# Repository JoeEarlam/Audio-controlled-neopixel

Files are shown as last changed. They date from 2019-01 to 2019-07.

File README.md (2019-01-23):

# Audio-controlled-neopixel

Filters an incoming line level audio signal into three bandpassed frequency "bins", which output to a peak detect sample and hold circuit. These sample and holds are sampled by the Arduino ADC, and the three frequencies (bass, mid, treble) become RGB on a Neopixel compatible LED strip.

There are a few different patterns currently written - a mixture of sound activated, random, block updated and "chasing lights" patterns.

# Hardware Notes, in no particular order.

There are two options for power. +5V only using a Tracopower TMA0512D to generate the +/-12V voltages required for the analogue components, or external +/-12V and 5V. 5V only is preferred for simplicity, but the TMA0512D isn't a typical parts bin find (and is the single most expensive component on the board), so an external power header has been added for operation without.

The level potentiometer allows a wide range of signals to be used. Turn it up until the peak light begins to flash, then down a little. This gives you maximum brightness from the Neopixel strip without clipping.

Follow Adafruit's guidance on Neopixel power supplies - the 5V rail will need to be beefy. The PCB can handle up to around 5A - ensure the fitted fuse is suitable.

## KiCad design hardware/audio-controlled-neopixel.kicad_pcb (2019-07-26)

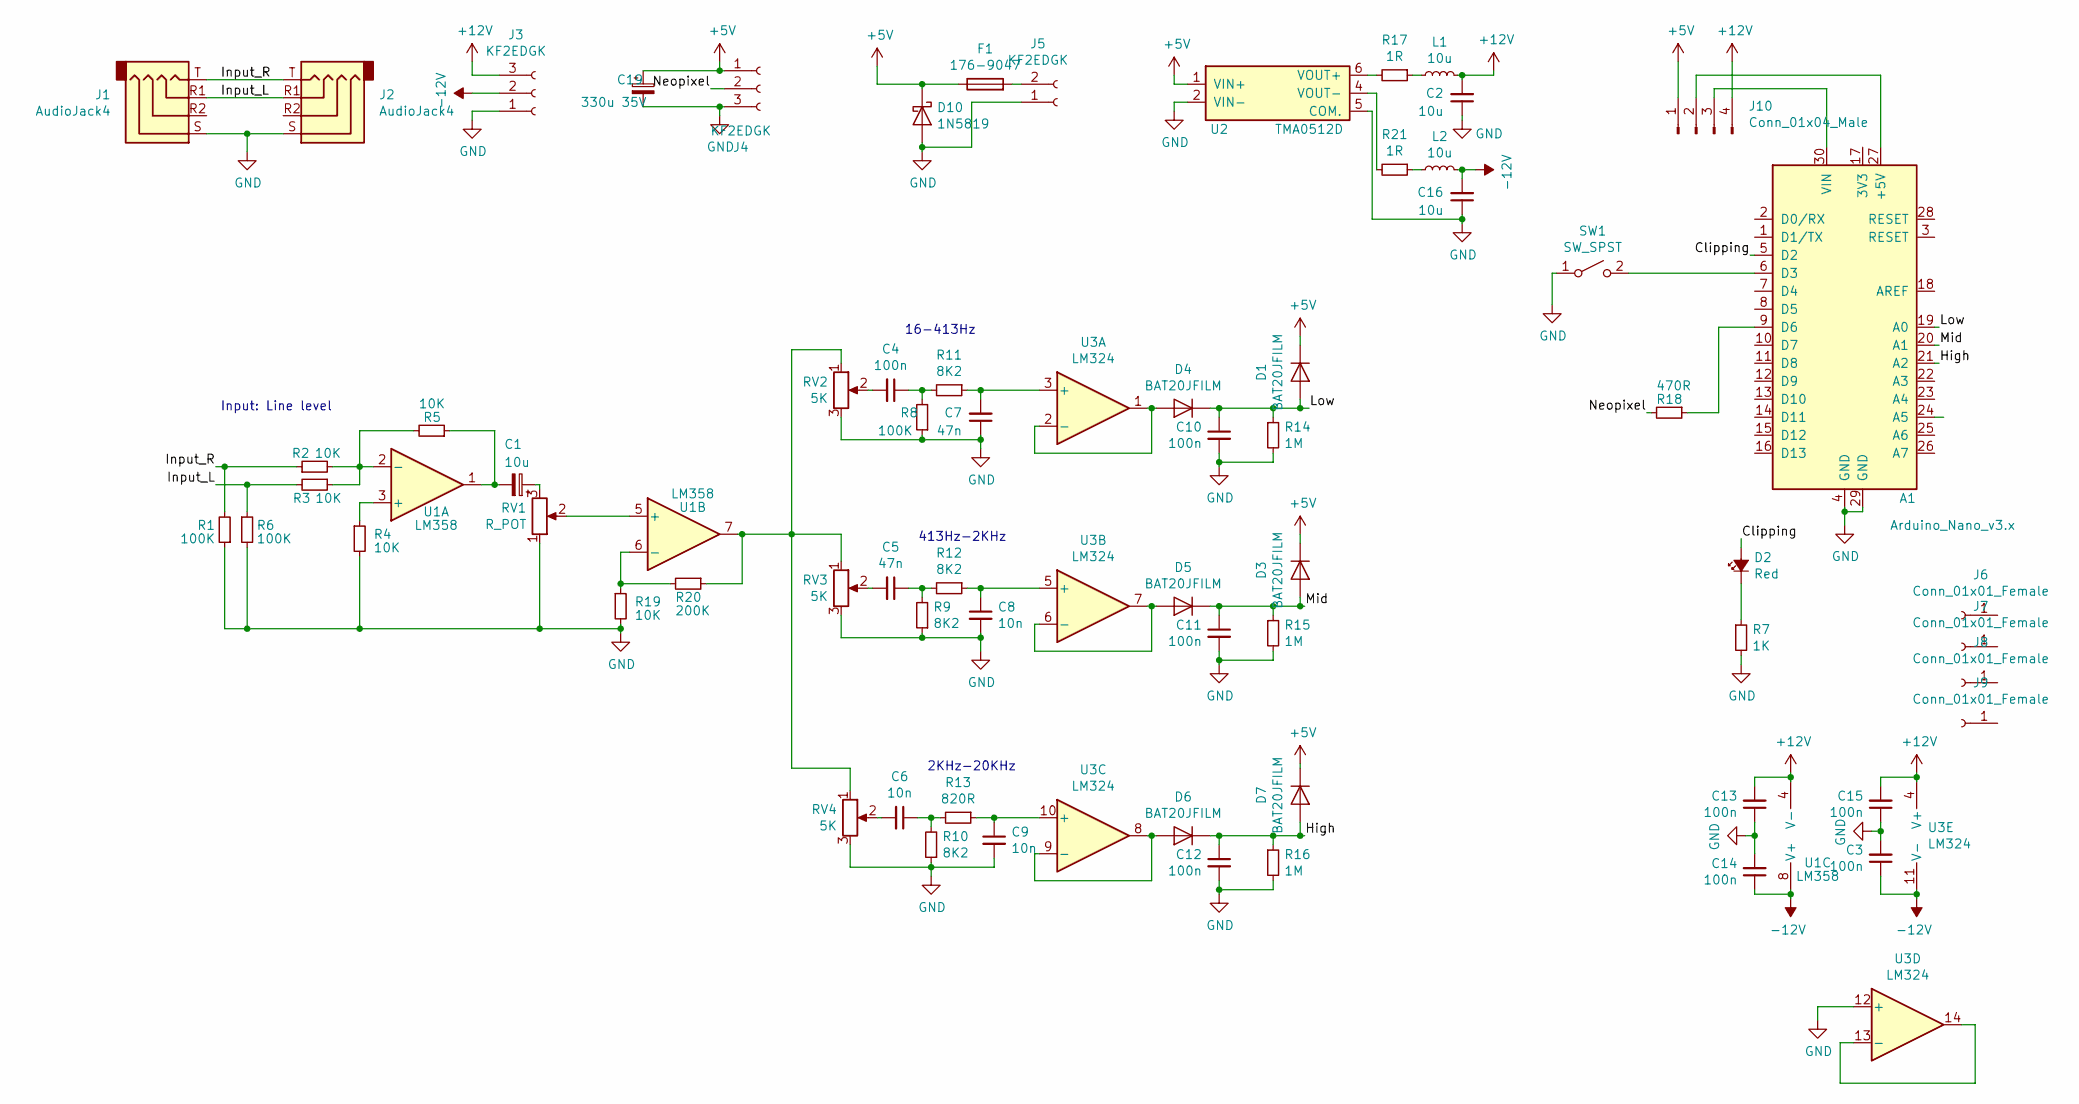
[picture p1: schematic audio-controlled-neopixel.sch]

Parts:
A1: Arduino_Nano_v3.x; Arduino_Nano
C1: 10u; CP_Radial_D5.0mm_P2.00mm
C2, C16: 10u; C_0805_2012Metric
C3, C4, C10, C11, C12, C13, C14, C15: 100n; C_0805_2012Metric
C5, C7: 47n; C_0805_2012Metric
C6, C8, C9: 10n; C_0805_2012Metric
C19: 330u 35V; CP_Elec_10x10
D1, D3, D4, D5, D6, D7: BAT20JFILM; D_SOD-323
D2: Red; LED_0805_2012Metric
D10: 1N5819; D_SOD-123
F1: 176-9047; 5x20_holder
J1, J2: AudioJack4; Jack_3.5mm_PJ320D_Horizontal
J3: KF2EDGK; TerminalBlock_Phoenix_MPT-0,5-3-2.54_1x03_P2.54mm_Horizontal
J4: KF2EDGK; PhoenixContact_MSTBA_2,5_3-G-5,08_1x03_P5.08mm_Horizontal
J5: KF2EDGK; PhoenixContact_MSTBA_2,5_2-G_1x02_P5.00mm_Horizontal
J6, J7, J8, J9: Conn_01x01_Female; MountingHole_3.2mm_M3
J10: Conn_01x04_Male; PinHeader_1x04_P2.54mm_Vertical
L1, L2: 10u; L_0805_2012Metric
R1, R6, R8: 100K; R_0805_2012Metric
R2, R3, R4, R5, R19: 10K; R_0805_2012Metric
R7: 1K; R_0805_2012Metric
R9, R10, R11, R12: 8K2; R_0805_2012Metric
R13: 820R; R_0805_2012Metric
R14, R15, R16: 1M; R_0805_2012Metric
R17, R21: 1R; R_0805_2012Metric
R18: 470R; R_0805_2012Metric
R20: 200K; R_0805_2012Metric
RV1: R_POT; Potentiometer_Alps_RK097_Single_Horizontal
RV2, RV3, RV4: 5K; Potentiometer_Vishay_TS53YJ_Vertical; Part Number EVM3YSX50B53
SW1: SW_SPST; SW_Tactile_SKHH_Angled
U1: LM358; SOIC-8_3.9x4.9mm_P1.27mm
U2: TMA0512D; TMAxxxxD; Manufacturer_Part_Number TMA 2412D; Mouser Part Number 495-TMA-2412D
U3: LM324; SOIC-14_3.9x8.7mm_P1.27mm

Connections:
+5V: C19.1, D1.1 (K), D3.1 (K), D7.1 (K), D10.1 (K), F1.1, J4.1, J10.1, U2.1 (VIN+)
+12V: C2.2, C13.2, C15.2, J3.3, J10.4, L1.2, U1.4 (V-), U3.4 (V+)
-12V: C3.1, C14.1, C16.2, J3.2, L2.2, U1.8 (V+), U3.11 (V-)
/Clipping: A1.5 (D2), D2.2 (A)
/High: A1.21 (A2), C12.1, D6.1 (K), D7.2 (A), R16.1
/Input_L: J1.R1, J2.R1, R3.2, R6.1
/Input_R: J1.T, J2.T, R1.2, R2.1
/Low: A1.19 (A0), C10.1, D1.2 (A), D4.1 (K), R14.1
/Mid: A1.20 (A1), C11.1, D3.2 (A), D5.1 (K), R15.1
/Neopixel: J4.2, R18.2
GND: A1.4 (GND), A1.29 (GND), C2.1, C3.2, C7.1, C8.2, C9.2, C10.2, C11.2, C12.2, C13.1, C14.2, C15.1, C16.1, C19.2, D10.2 (A), J1.S, J2.S, J3.1, J4.3, J5.1, R1.1, R4.2, R6.2, R7.2, R8.1, R9.1, R10.1, R14.2, R15.2, R16.2, R19.2, RV1.1, RV2.3, RV3.3, RV4.3, SW1.1 (A), U2.2 (VIN-), U2.5 (COM.), U3.12 (+)
unnamed: A1.6 (D3), SW1.2 (B)
unnamed: A1.9 (D6), R18.1
unnamed: A1.27 (+5V), J10.2
unnamed: A1.30 (VIN), J10.3
unnamed: C1.1, RV1.3
unnamed: C1.2, R5.1, U1.1
unnamed: C4.1, R8.2, R11.2
unnamed: C4.2, RV2.2
unnamed: C5.1, R9.2, R12.2
unnamed: C5.2, RV3.2
unnamed: C6.1, R10.2, R13.2
unnamed: C6.2, RV4.2
unnamed: C7.2, R11.1, U3.3 (+)
unnamed: C8.1, R12.1, U3.5 (+)
unnamed: C9.1, R13.1, U3.10 (+)
unnamed: D2.1 (K), R7.1
unnamed: D4.2 (A), U3.1, U3.2 (-)
unnamed: D5.2 (A), U3.6 (-), U3.7
unnamed: D6.2 (A), U3.8, U3.9 (-)
unnamed: F1.2, J5.2
unnamed: L1.1, R17.1
unnamed: L2.1, R21.1
unnamed: R2.2, R3.1, R5.2, U1.2 (-)
unnamed: R4.1, U1.3 (+)
unnamed: R17.2, U2.6 (VOUT+)
unnamed: R19.1, R20.2, U1.6 (-)
unnamed: R20.1, RV2.1, RV3.1, RV4.1, U1.7
unnamed: R21.2, U2.4 (VOUT-)
unnamed: RV1.2, U1.5 (+)
unnamed: U3.13 (-), U3.14

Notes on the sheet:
16-413Hz
413Hz-2KHz
2KHz-20KHz
Input: Line level

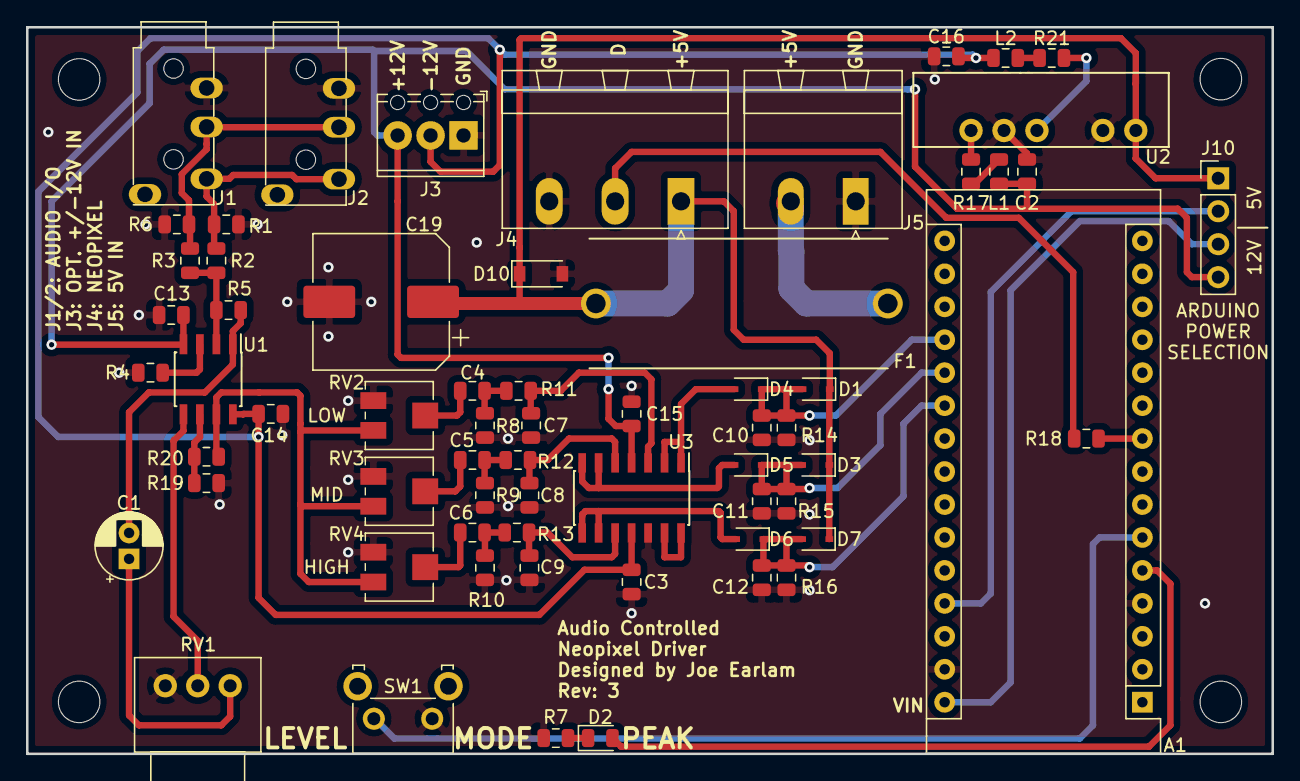
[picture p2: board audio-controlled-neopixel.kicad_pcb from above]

Board: 2 copper layers, 96.0 x 56.0 mm, 68 parts (0 on the bottom side), 41 nets.

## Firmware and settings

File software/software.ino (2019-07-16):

#include <Adafruit_NeoPixel.h>
#ifdef __AVR__
  #include <avr/power.h>
#endif


/////////////////////////Number of pixels in your strip
const byte numpixels = 152; 

const byte clipping = 2;
const byte button = 3;        //button pin
const byte pin = 6;           //Neopixel pin

boolean buttonState;          //current state of button
boolean lastButtonState;      //previous state of button

byte red;                     //red pixel value
byte green;                   //green...
int blue;                    //etc
byte programme;               //current programme type (0 = block, 1 = chasing lights)

byte pixelarray[numpixels][3];    //2D Array to hold status of every pixel

Adafruit_NeoPixel pixels = Adafruit_NeoPixel(numpixels, pin, NEO_RGB + NEO_KHZ800);		//set up strip


//Table for gamma correction, this adjusts brightness values for more visual contrast
const uint8_t PROGMEM gamma8[] = {
    0,  0,  0,  0,  0,  0,  0,  0,  0,  0,  0,  0,  0,  0,  0,  0,
    0,  0,  0,  0,  0,  0,  0,  0,  0,  0,  0,  0,  1,  1,  1,  1,
    1,  1,  1,  1,  1,  1,  1,  1,  1,  2,  2,  2,  2,  2,  2,  2,
    2,  3,  3,  3,  3,  3,  3,  3,  4,  4,  4,  4,  4,  5,  5,  5,
    5,  6,  6,  6,  6,  7,  7,  7,  7,  8,  8,  8,  9,  9,  9, 10,
   10, 10, 11, 11, 11, 12, 12, 13, 13, 13, 14, 14, 15, 15, 16, 16,
   17, 17, 18, 18, 19, 19, 20, 20, 21, 21, 22, 22, 23, 24, 24, 25,
   25, 26, 27, 27, 28, 29, 29, 30, 31, 32, 32, 33, 34, 35, 35, 36,
   37, 38, 39, 39, 40, 41, 42, 43, 44, 45, 46, 47, 48, 49, 50, 50,
   51, 52, 54, 55, 56, 57, 58, 59, 60, 61, 62, 63, 64, 66, 67, 68,
   69, 70, 72, 73, 74, 75, 77, 78, 79, 81, 82, 83, 85, 86, 87, 89,
   90, 92, 93, 95, 96, 98, 99,101,102,104,105,107,109,110,112,114,
  115,117,119,120,122,124,126,127,129,131,133,135,137,138,140,142,
  144,146,148,150,152,154,156,158,160,162,164,167,169,171,173,175,
  177,180,182,184,186,189,191,193,196,198,200,203,205,208,210,213,
  215,218,220,223,225,228,231,233,236,239,241,244,247,249,252,255 };

void setup() {
  pinMode(button,INPUT);
  pinMode(clipping,OUTPUT);
  Serial.begin(9600);
  pixels.begin(); // This initializes the NeoPixel library.
}

void loop() 
{

  //change programme type on button press (rising edge trigger only)
  buttonState = digitalRead(button);
  if (buttonState != lastButtonState) 
  {
    if (buttonState == HIGH)
    {
      programme++;
      if(programme > 4) //Set highest programme number here
      {
        programme = 0;
      }
    }
    delay(50);
  }
  lastButtonState = buttonState;

  int rawRed = analogRead(0);
  int rawGreen = analogRead(1);
  int rawBlue = analogRead(2);
  
  if((rawRed == 1023 || rawGreen == 1023 || rawBlue == 1023))
  {
    digitalWrite(clipping,HIGH);
  }
  else
  {
    digitalWrite(clipping,LOW);
  }
  
  //Saves current RGB values to memory for use by routines
  red = pgm_read_byte(&gamma8[rawRed/4]);    //Red is A0/4 (0-255 output, 0-1023 input)
  green = pgm_read_byte(&gamma8[rawGreen/4]);   //Green is A1/4
  blue = pgm_read_byte(&gamma8[rawBlue/4]);   //Blue is A2/4

  if(programme == 0) //dimming chasing lights
    {
      //First pixel in the chain is set to our latest colours
      pixelarray[0][0] = red;
      pixelarray[0][1] = green;
      pixelarray[0][2] = blue;
      
     //Goes through our bigass array and assigns values to every pixel as per the contents of the array
     for(byte i=0;i<numpixels;i++)
      {
        pixels.setPixelColor(i, pixels.Color(pixelarray[i][0],pixelarray[i][1],pixelarray[i][2]));
      }
      
      pixels.show(); // This sends the updated pixel color to the hardware.
    
      //shifts values in array up by one, leaving space for new values at start of strip. This gives our "chasing" effect
      for(byte i=0;i<3;i++)
      {
        for(byte j = numpixels-1; j>0; j--)
        {
          if((pixelarray[j-1][i]) > 15)
          {
            pixelarray[j][i] = pixelarray[j-1][i] -15;
          }
          else if((pixelarray[j-1][i]) > 2)
          {
            pixelarray[j][i] = pixelarray[j-1][i] -2;
          }
          else
          {
            pixelarray[j][i] = pixelarray[j-1][i];
          }
        }
      }
    
    delay(10);  //Delay some time, otherwise things happen too fast to see
  }

  if(programme == 1) //chasing lights
  {
    //First pixel in the chain is set to our latest colours
    pixelarray[0][0] = red;
    pixelarray[0][1] = green;
    pixelarray[0][2] = blue;
    
   //Goes through our bigass array and assigns values to every pixel as per the contents of the array
   for(byte i=0;i<numpixels;i++)
    {
      pixels.setPixelColor(i, pixels.Color(pixelarray[i][0],pixelarray[i][1],pixelarray[i][2]));
    }
    
    pixels.show(); // This sends the updated pixel color to the hardware.
  
    //shifts values in array up by one, leaving space for new values at start of strip. This gives our "chasing" effect
    for(byte i=0;i<3;i++)
    {
      for(byte j = numpixels-1; j>0; j--)
      {
        pixelarray[j][i] = pixelarray[j-1][i];
      }
    }
    
    delay(10);  //Delay some time, otherwise things happen too fast to see
  }

  if(programme == 2) //block update
  {
    
    //Assigns every pixel value to our RGB values
    for(byte i=0; i<numpixels; i++)
    {
      pixels.setPixelColor(i, pixels.Color(red,green,blue));
    }

    pixels.show(); // This sends the updated pixel color to the hardware.
  }

  if(programme == 3) //random dimming chase (no audio control)
  {
      //First pixel in the chain is set to our latest colours
      pixelarray[0][0] = random(255);
      pixelarray[0][1] = random(255);
      pixelarray[0][2] = random(255);
      
     //Goes through our bigass array and assigns values to every pixel as per the contents of the array
     for(byte i=0;i<numpixels;i++)
      {
        pixels.setPixelColor(i, pixels.Color(pixelarray[i][0],pixelarray[i][1],pixelarray[i][2]));
      }
      
      pixels.show(); // This sends the updated pixel color to the hardware.
    
      //shifts values in array up by one, leaving space for new values at start of strip. This gives our "chasing" effect
      for(byte i=0;i<3;i++)
      {
        for(byte j = numpixels-1; j>0; j--)
        {
          if((pixelarray[j-1][i]) > 5)          //reduce intensity 5 after every shift
          {
            pixelarray[j][i] = pixelarray[j-1][i] -5;
          }
          else
          {
            pixelarray[j][i] = pixelarray[j-1][i];
          }
        }
      }
      delay(100);  //Delay some time, otherwise things happen too fast to see
    }

  if(programme == 4)
  {
    
    //Assigns every pixel value to our RGB values
    for(byte i=0; i<numpixels; i++)
    {
      pixels.setPixelColor(i, pixels.Color(random(255),random(255),random(255)));
    }

    pixels.show(); // This sends the updated pixel color to the hardware.
    delay(100);
  }
    
}

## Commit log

2018-11-14 Tweaked filter values for treble in schematic, added gamma correction for LEDs.
    [audio-controlled-neopixel.sch]
2018-11-15 Updated schematic and PCB to use SMD components for ease of manufacture.
    [BOM.xlsx, Basket_Oct31_0519AM.xls, audio-controlled-neopixel.kicad_pcb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]
2018-11-15 Fixed minor PCB trace issues
    [audio-controlled-neopixel.kicad_pcb]
2018-11-15 Added pdf schematic
    [audio-controlled-neopixel.sch]
2019-01-14 updated schematic to reduce component count, PCB update to match
    [BOM.xlsx, audio-controlled-neopixel.kicad_pcb, audio-controlled-neopixel.sch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]
2019-01-14 minor PCB clean up
    [audio-controlled-neopixel.kicad_pcb]
2019-01-15 update schematic to use 3.5mm audio I/O
    [_saved_audio-controlled-neopixel.sch, audio-controlled-neopixel.kicad_pcb, audio-controlled-neopixel_bom_.csv]
2019-01-15 clean up schematic and PCB
    [audio-controlled-neopixel.kicad_pcb, audio-controlled-neopixel.sch]
2019-01-15 add attenuator for peak level calibration
    [audio-controlled-neopixel.kicad_pcb, audio-controlled-neopixel.sch]
2019-01-23 updated some footprints and symbols
    [audio-controlled-neopixel.kicad_pcb, audio-controlled-neopixel.sch]
2019-01-23 PCB bugfix, rearranged code
    [audio-controlled-neopixel.kicad_pcb]
2019-01-27 added frequency response graph
    [frequency response.ods]
2019-01-27 added attenuators to keep frequency response flat
    [audio-controlled-neopixel.sch]
2019-01-28 Hacky fix for less sensitive blue channel
    [software.ino]
2019-01-29 Updated frequency response graph
    [frequency response.ods]
2019-01-30 fixed library issue with schematic
    [audio-controlled-neopixel.sch]
2019-02-04 added attenuators to balance frequency response
    [audio-controlled-neopixel.kicad_pcb, audio-controlled-neopixel.sch]
2019-02-05 removed analogue clipping hardware to prepare for transisiton to software solution (not implemented)
    [audio-controlled-neopixel.kicad_pcb, audio-controlled-neopixel.sch]
2019-02-07 tag for prototype production
    [audio-controlled-neopixel.kicad_pcb]
2019-02-07 minor silkscreen changes
    [audio-controlled-neopixel.kicad_pcb]
2019-02-13 added input resistors
    [audio-controlled-neopixel.kicad_pcb, audio-controlled-neopixel.sch]
2019-02-19 Cleaned up schematic, refactored code for latest hardware
    [audio-controlled-neopixel.sch]
2019-02-28 connect both op-amps to dual supply
    [audio-controlled-neopixel.kicad_pcb, audio-controlled-neopixel.sch]
2019-03-05 adjusted component values for better real world performance, changed diode types, minor PCB changes for better ground return paths
    [audio-controlled-neopixel.kicad_pcb, audio-controlled-neopixel.sch]
2019-03-10 updated software so clipping LED actually works
2019-07-16 hardware updates
    [audio-controlled-neopixel.kicad_pcb, audio-controlled-neopixel.sch]
2019-07-16 added power supply filtering
    [audio-controlled-neopixel.kicad_pcb, audio-controlled-neopixel.sch]
2019-07-26 as sent to production 26/07/19
    [audio-controlled-neopixel.kicad_pcb, audio-controlled-neopixel.sch]
